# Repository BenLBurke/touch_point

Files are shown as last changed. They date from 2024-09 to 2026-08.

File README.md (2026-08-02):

# Disney Touch Point
Using NFC technology, I want to create the Touch Point Disney offers at its entrances for my own personal use at home.   

To include upon read:
- Lights
- Sounds

# Wiring
### [RFID-RC522]([url](https://www.aliexpress.us/item/3256807702682933.html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))
Standard hardware SPI0 wiring — this is what `touchpoint/hardware.py`'s `init_reader()` (via the `mfrc522` library's `SimpleMFRC522`) expects by default, so no pin numbers need to be set in code or config.

| RC522 Pin | Pi Pin (BCM / physical) | Notes |
| --- | --- | --- |
| SDA / NSS | GPIO8 / Pin 24 (SPI0 CE0) | Chip select |
| SCK | GPIO11 / Pin 23 (SPI0 SCLK)  | Clock |
| MOSI | GPIO10 / Pin 19 (SPI0 MOSI)  | Data to RC522 |
| MISO | GPIO9 / Pin 21 (SPI0 MISO) | Data from RC522 |
| IRQ | *not connected* | Unused — `SimpleMFRC522` polls the reader instead  |
| RST | GPIO25 / Pin 22 | Reset — matches the `mfrc522` library's default |
| 3.3V | Pin 1 or 17 | **3.3V only** — the RC522 is not 5V tolerant |
| GND | Pin 6 (or any GND pin) | Ground |

### WS2812B / NeoPixel ring
Data pin matches `TOUCHPOINT_PIXEL_PIN` in `touchpoint/config.py` (default `D18`).

| WS2812B Pin | Pi Pin (BCM / physical) | Notes |
| --- | --- | --- |
| 5V | External 5V supply — **not** the Pi's 5V pin | See power note below |
| DIN | GPIO18 / Pin 12 (PWM0) | Matches `TOUCHPOINT_PIXEL_PIN=D18` |
| GND | Shared with Pi GND (e.g. Pin 6) | The LED supply and the Pi must share a common ground |

**Power & signal notes (worth following even if it "seems to work" without them):**
- Don't power the ring off the Pi's own 5V pin. 48 pixels at full white can draw close to 3A — more than the Pi's onboard regulator (and often the upstream power supply) can deliver, which causes brownouts that silently reset the Pi mid-effect. Give the ring its own 5V supply, sized for your pixel count (~60mA/pixel at full white is a safe planning number), and tie that supply's ground to the Pi's ground.
- The Pi's GPIO is 3.3V logic driving a data line the WS2812B spec expects at 5V. For a short run inside one enclosure this is usually fine as-is. If you see flickering or wrong colors, add a logic-level shifter (e.g. 74AHCT125) on the data line and a ~300-470Ω resistor in series right at the first pixel — both are standard WS2812 fixes.
- A ~1000µF capacitor across 5V/GND at the start of the strip absorbs the inrush current spike when all pixels switch on at once.

To run:
```bash
sudo ~/touch_point/venv/bin/python touch_point.py
```

# Project layout
- `touch_point.py` — main entry point: the RFID scan loop.
- `touchpoint/` — the actual app logic, split so it can be unit tested without a Pi:
  - `config.py` — all tunables, overridable via environment variables (see below).
  - `effects.py` — pure LED ring animations (take a `pixels` object as an argument).
  - `sounds.py` — the sound library and which animation each tag/sound maps to.
  - `hardware.py` — the only place that touches real GPIO/SPI/audio hardware.
- `tests/` — automated `pytest` suite. Runs on any machine; hardware libraries are faked out.
- `hardware_checks/` — small manual scripts for bringing up one piece of hardware at a time on a real Pi (not run by `pytest`).
- `commands/` — deployment scripts (`setup_script.sh`, `pull.sh` for the pm2/cron update loop).

# Configuration (environment variables)
| Variable | Default | Purpose |
| --- | --- | --- |
| `TOUCHPOINT_NUM_PIXELS` | `48` | Number of LEDs on the ring |
| `TOUCHPOINT_PIXEL_PIN` | `D18` | `board` attribute name for the NeoPixel data pin |
| `TOUCHPOINT_BRIGHTNESS` | `0.4` | NeoPixel brightness, 0–1 |
| `TOUCHPOINT_AUDIO_DRIVER`  | `alsa` | SDL audio driver |
| `TOUCHPOINT_AUDIO_DEVICE`  | `plughw:2,0` | ALSA device for the USB sound card (see `aplay -l`) |
| `TOUCHPOINT_SOUND_DIR` | `sound_files/` | Directory containing the wav files |
| `TOUCHPOINT_LOG_FILE` | `touch_point.log` | Log file path |

Set them before launch instead of editing code, e.g.:
```bash
TOUCHPOINT_AUDIO_DEVICE=plughw:1,0 sudo -E ~/touch_point/venv/bin/python touch_point.py
```

# Tests
```bash
python3 -m venv .venv && source .venv/bin/activate
pip install -r requirements-dev.txt
pytest
```
The suite fakes out `board`, `neopixel`, `pygame`, and `mfrc522`, so it runs on a laptop/CI with no Pi or wired hardware attached. A GitHub Actions workflow (`.github/workflows/tests.yml`) runs it on every push.

# Will this work on a Raspberry Pi Zero?
Yes. The Pi Zero W and Zero 2 W run the same Raspberry Pi OS as the 3/4/5, expose the same 40-pin header, and `touch_point.py` runs on them unmodified. A few practical notes:

- **Prefer a Pi Zero 2 W.** The original Zero/Zero W is single-core ARM11 @ 1GHz. Driving the WS2812 ring uses a timing-sensitive DMA+PWM signal, and running that alongside pygame's audio mixer and SPI polling for the RFID reader on one core can cause occasional flicker or audio glitches. The quad-core Zero 2 W has enough headroom that this isn't an issue.
- **Audio needs a USB sound card.** Neither Zero model has a 3.5mm jack, so plug a USB audio dongle in through a USB-OTG hub (the Zero has a single micro-USB data port, no built-in Ethernet or full-size USB). Run `sudo aplay -l` to find its card/device index and set `TOUCHPOINT_AUDIO_DEVICE=plughw:<card>,<device>` instead of editing the code.
- **Power the LED ring separately.** Don't pull NeoPixel power from the Pi's 5V pin — the Zero's regulator can't supply a 48-LED ring at brightness. Feed 5V/GND to the ring from an external supply and only share ground with the Pi, same as on any other Pi model.
- **SPI wiring is identical** to the RC522 table above.
- **`commands/setup/setup_script.sh` works unchanged** — it only uses `apt`/`raspi-config`, which are the same across Pi models.

# [3D Print of Reader](https://www.thingiverse.com/thing:4549215)

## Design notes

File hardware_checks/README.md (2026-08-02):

# Hardware checks

Small, standalone scripts for bringing up and sanity-checking one piece
of physical hardware at a time. They require real hardware attached to
a Raspberry Pi (or, for `pico_pn532/`, a MicroPython board) and are run
manually -- they are **not** part of the automated `pytest` suite in
`tests/`.

- `led_test.py` -- cycles the NeoPixel ring through red/green/blue.
- `comet.py` -- spins a comet-tail animation on the ring.
- `rfid_test.py` -- reads and prints RFID tag IDs in a loop.
- `sound_test.py` -- plays a WAV to confirm the audio output is wired up.
- `tag_pixels_test.py` -- combined RFID + LED demo (non-blocking read).
- `pico_pn532/` -- an earlier prototype using a PN532 NFC module driven
  from MicroPython on a separate microcontroller (e.g. a Pi Pico), not
  the RC522 + Raspberry Pi setup `touch_point.py` uses today. Kept for
  reference.

Run any of them the same way you'd run `touch_point.py`, e.g.:

```bash
sudo ~/touch_point/venv/bin/python hardware_checks/led_test.py
```

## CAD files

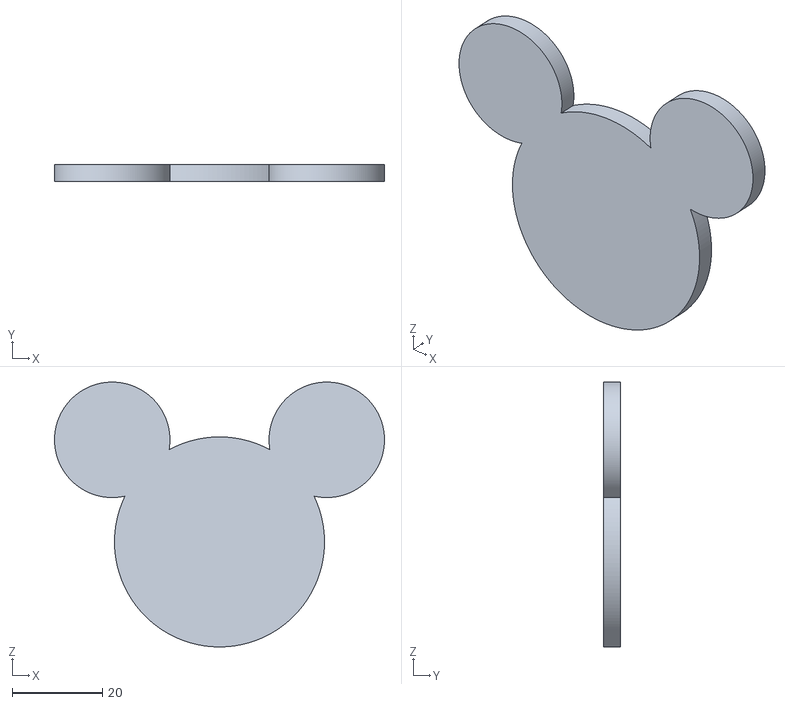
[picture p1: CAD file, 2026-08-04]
print_file/mickey.stl
72.9 x 3.81 x 58.5

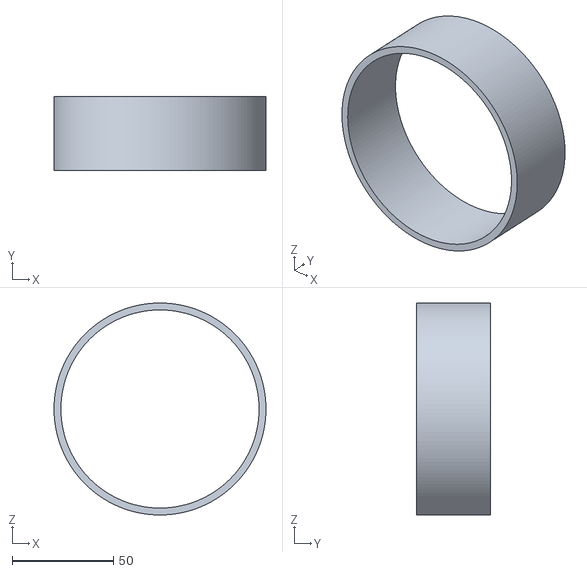
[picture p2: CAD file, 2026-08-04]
print_file/outer-ring.stl
104.7 x 36.6 x 104.7

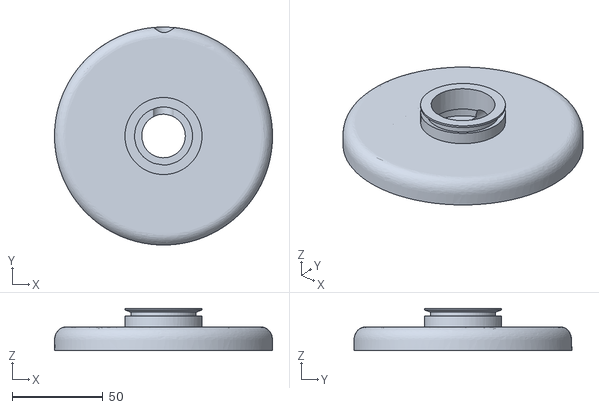
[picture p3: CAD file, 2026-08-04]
print_file/reader_base.stl
120.0 x 120.0 x 23.3

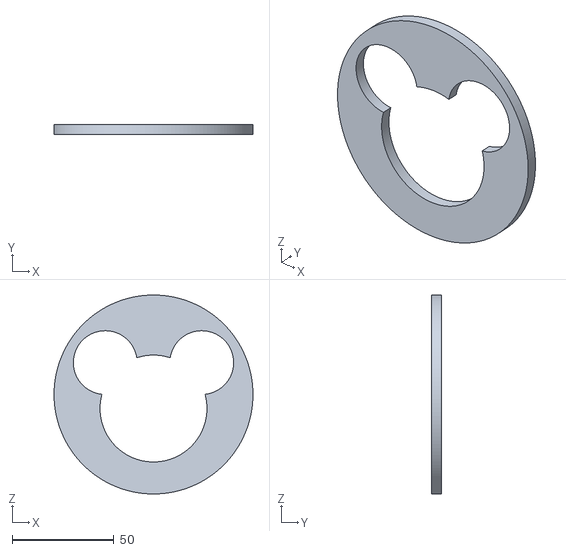
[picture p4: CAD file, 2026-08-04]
print_file/mickey-face.stl
97.8 x 4.83 x 97.8

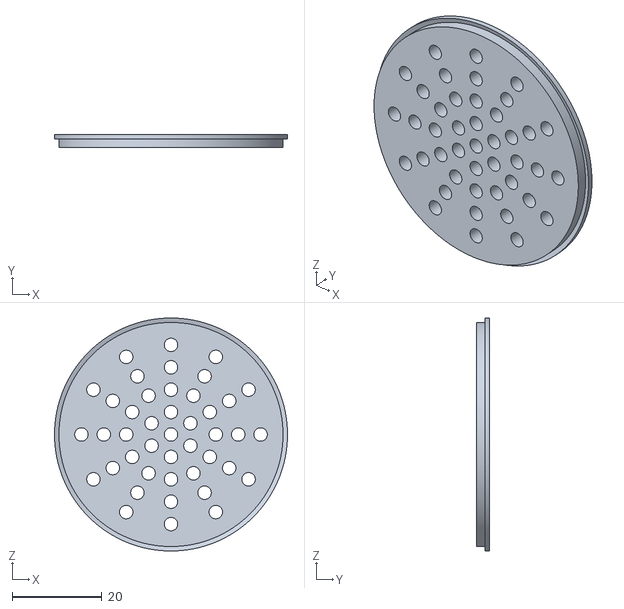
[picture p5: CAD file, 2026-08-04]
print_file/speaker_grille.stl
52.0 x 3.00 x 52.0

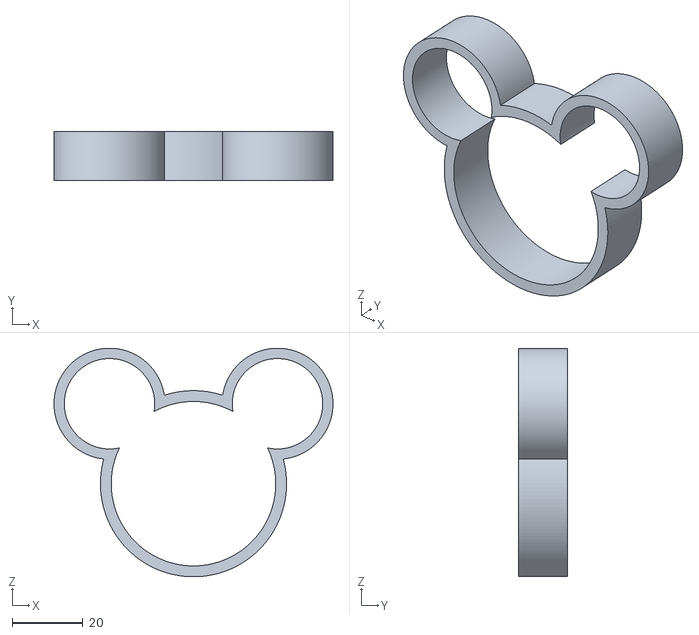
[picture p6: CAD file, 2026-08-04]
print_file/mouse-outline.stl
78.8 x 14.0 x 64.5

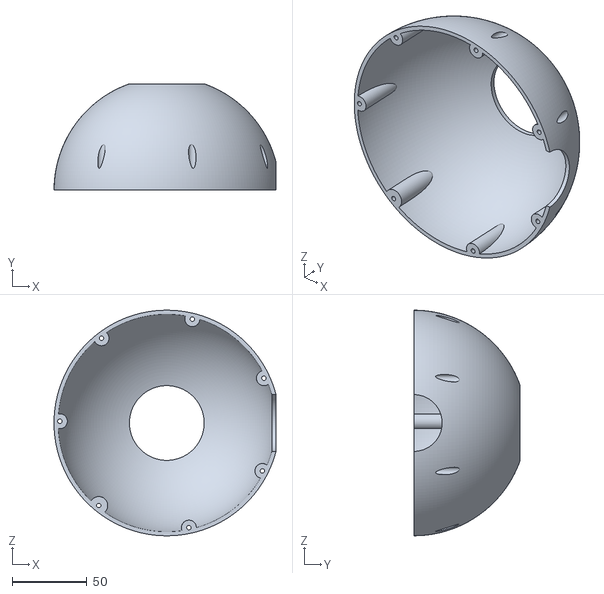
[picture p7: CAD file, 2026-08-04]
print_file/back_Speaker.stl
148.6 x 71.3 x 151.0

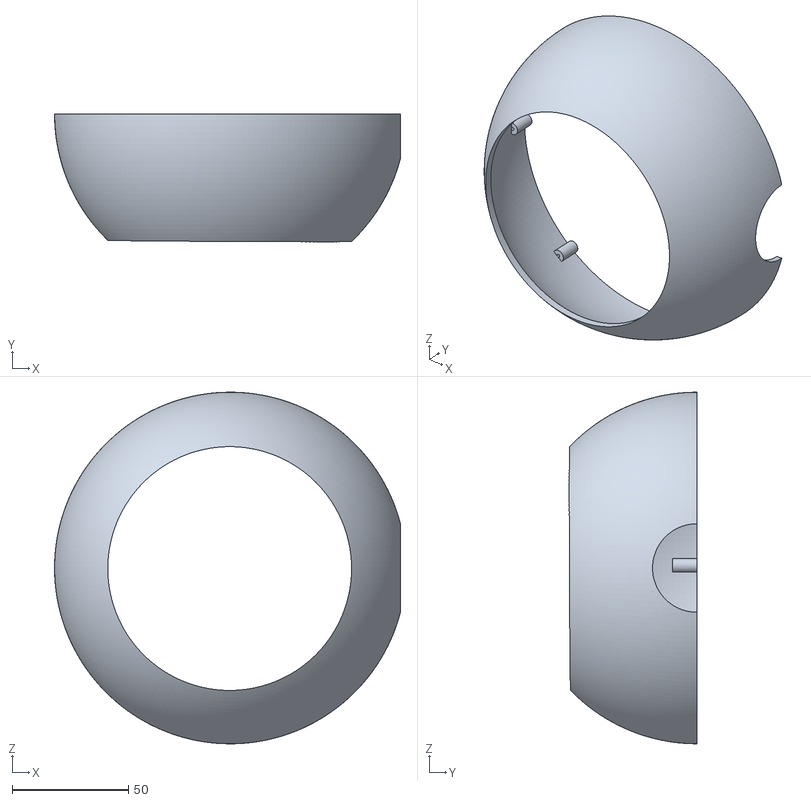
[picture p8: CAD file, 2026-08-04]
print_file/Front_screws.stl
148.6 x 54.8 x 151.0

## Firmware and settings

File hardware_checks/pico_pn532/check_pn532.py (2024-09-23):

import NFC_PN532 as nfc
from machine import Pin, SPI

# SPI
spi_dev = SPI(0, baudrate=400000, sck=Pin(18), mosi=Pin(19), miso=Pin(16))
cs = Pin(17, Pin.OUT)
cs.on()

# SENSOR INIT
pn532 = nfc.PN532(spi_dev,cs)
ic, ver, rev, support = pn532.get_firmware_version()
print('Found PN532 with firmware version: {0}.{1}'.format(ver, rev))

# Configure PN532 to communicate with MiFare cards
pn532.SAM_configuration()

# FUNCTION TO READ 
def read_nfc(dev, tmot):
    """Accepts a device and a timeout in millisecs """
    print('Reading...')
    uid = dev.read_passive_target(timeout=tmot)
    if uid is None:
        print('CARD NOT FOUND')
    else:
        numbers = [i for i in uid]
        string_ID = '{}-{}-{}-{}'.format(*numbers)
        print('Found card with UID:', [hex(i) for i in uid])
        if string_ID == '4-21-114-154':
            print("Hi Jack!")
        if string_ID == '207-231-213-76':
            print('Hi Cora!')
        if string_ID == '4-233-116-167':
            print('Hi Jane!')
        print('Number_id: {}'.format(string_ID))

while True:
    read_nfc(pn532, 500)
  

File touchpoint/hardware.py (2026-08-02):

"""Real hardware bring-up: NeoPixel ring, RFID reader, and audio.

Every hardware library is imported lazily, inside these functions, not
at module import time. That means ``touchpoint.hardware`` -- and the
pure ``touchpoint.effects`` / ``touchpoint.sounds`` modules it sits on
top of -- can be imported and unit tested on a regular dev machine with
no Blinka/SPI/audio hardware attached: tests simply put fake modules in
``sys.modules`` before calling these functions.
"""
import logging
import os

from . import config, sounds

logger = logging.getLogger(__name__)


def init_pixels():
    import board
    import neopixel

    pin = getattr(board, config.PIXEL_PIN_NAME)
    pixels = neopixel.NeoPixel(
        pin, config.NUM_PIXELS, brightness=config.BRIGHTNESS, auto_write=False
    )
    logger.info("NeoPixel ring ready: %d pixels on %s", config.NUM_PIXELS, config.PIXEL_PIN_NAME)
    return pixels


def init_reader():
    from mfrc522 import SimpleMFRC522

    reader = SimpleMFRC522()
    logger.info("RFID reader ready")
    return reader


def init_audio():
    # Must be set before pygame/SDL touches the audio subsystem.
    os.environ["SDL_AUDIODRIVER"] = config.AUDIO_DRIVER
    os.environ["AUDIODEV"] = config.AUDIO_DEVICE

    import pygame

    pygame.mixer.pre_init(frequency=44100, size=-16, channels=2, buffer=512)
    pygame.mixer.init()
    logger.info("Audio ready: driver=%s device=%s", config.AUDIO_DRIVER, config.AUDIO_DEVICE)
    return pygame


def load_sound(pygame_module, path, volume: float = 1.0):
    """Load a WAV and set its volume (0.0 to 1.0)."""
    sound = pygame_module.mixer.Sound(str(path))
    sound.set_volume(volume)
    return sound


def load_all_sounds(pygame_module):
    """Load the tap sound plus every clip in the sound library.

    Returns (tap_sound, {name: {"song": Sound, "length": int}}).
    """
    tap_sound = load_sound(pygame_module, config.SOUND_DIR / sounds.TAP_SOUND_FILENAME)
    library = {
        clip.name: {
            "song": load_sound(pygame_module, config.SOUND_DIR / clip.filename),
            "length": clip.length,
        }
        for clip in sounds.SOUND_LIBRARY
    }
    return tap_sound, library

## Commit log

2025-08-15 adding stop_us_now and led animation
2026-08-02 Refactor into a testable package, add pytest suite + CI, document Pi Zero support
    * Refactor into a testable package, add pytest suite + CI, document Pi Zero support
    - Split touch_point.py into a touchpoint/ package: config (env-var driven
    settings), effects (pure LED animations that take a pixels object),
    sounds (data-driven sound/effect catalogue), and hardware (the only
    module that imports board/neopixel/mfrc522/pygame, done lazily so
    everything else is importable without a Pi attached).
    - Make touch_point.py resilient: hardware init failures and RFID read
    errors are logged instead of crashing, SIGTERM triggers a clean
    shutdown (pixels cleared, mixer closed) alongside the exi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
    [check_pn532.py, comet.py, config.py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]
2026-08-04 Create print_files
2026-08-04 adding print files
    [Copy of magic_band_base (1).stl, Front_screws.stl, back_Speaker.stl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]
2026-08-04 Rename Copy of magic_band_base (1).stl to reader_base
2026-10-29 Reopen the speaker on every tap so sound recovers after a dropout
    A USB speaker on a Pi Zero can drop off the bus and re-enumerate (a
    brief power dip is enough). The mixer was opened once at startup, so
    after that it kept writing to the dead device and stayed silent until
    the app was restarted. Now each tap reopens the speaker and loads its
    two clips fresh; if the speaker is missing, the tap plays lights only
    instead of crashing the app.
    Claude-Session: https://claude.ai/code/session_016hYBVG4ZGXpZFXGZP6PcZP
2026-10-31 Fix audio underruns and RFID AUTH ERROR spam
    Raise the mixer buffer from 512 to 4096 samples (configurable via
    TOUCHPOINT_AUDIO_BUFFER): on a single-core Pi Zero the LED animations
    starve the audio thread, and the logs filled with ALSA underruns.
    Read tags with read_id() instead of read(). read() also tries to
    authenticate with the default MIFARE key to read the tag's text, which
    fails on MagicBands ("AUTH ERROR!!"); the app only uses the UID.
    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
